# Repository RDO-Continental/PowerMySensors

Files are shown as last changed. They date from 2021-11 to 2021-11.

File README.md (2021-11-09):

# PowerMySensors
Code de notre module de mesure de puissance (Arduino + NRF + MySensors)

Mesure de puissance club RDO : MPRDO V1.0
 * Alimenté par un transfo qui sert aussi à la mesure de la puissance reelle.
 * Transmission par module NRF24L01 et protocole Mysensors
 * Basé sur le projet "openenergymonitor.org"

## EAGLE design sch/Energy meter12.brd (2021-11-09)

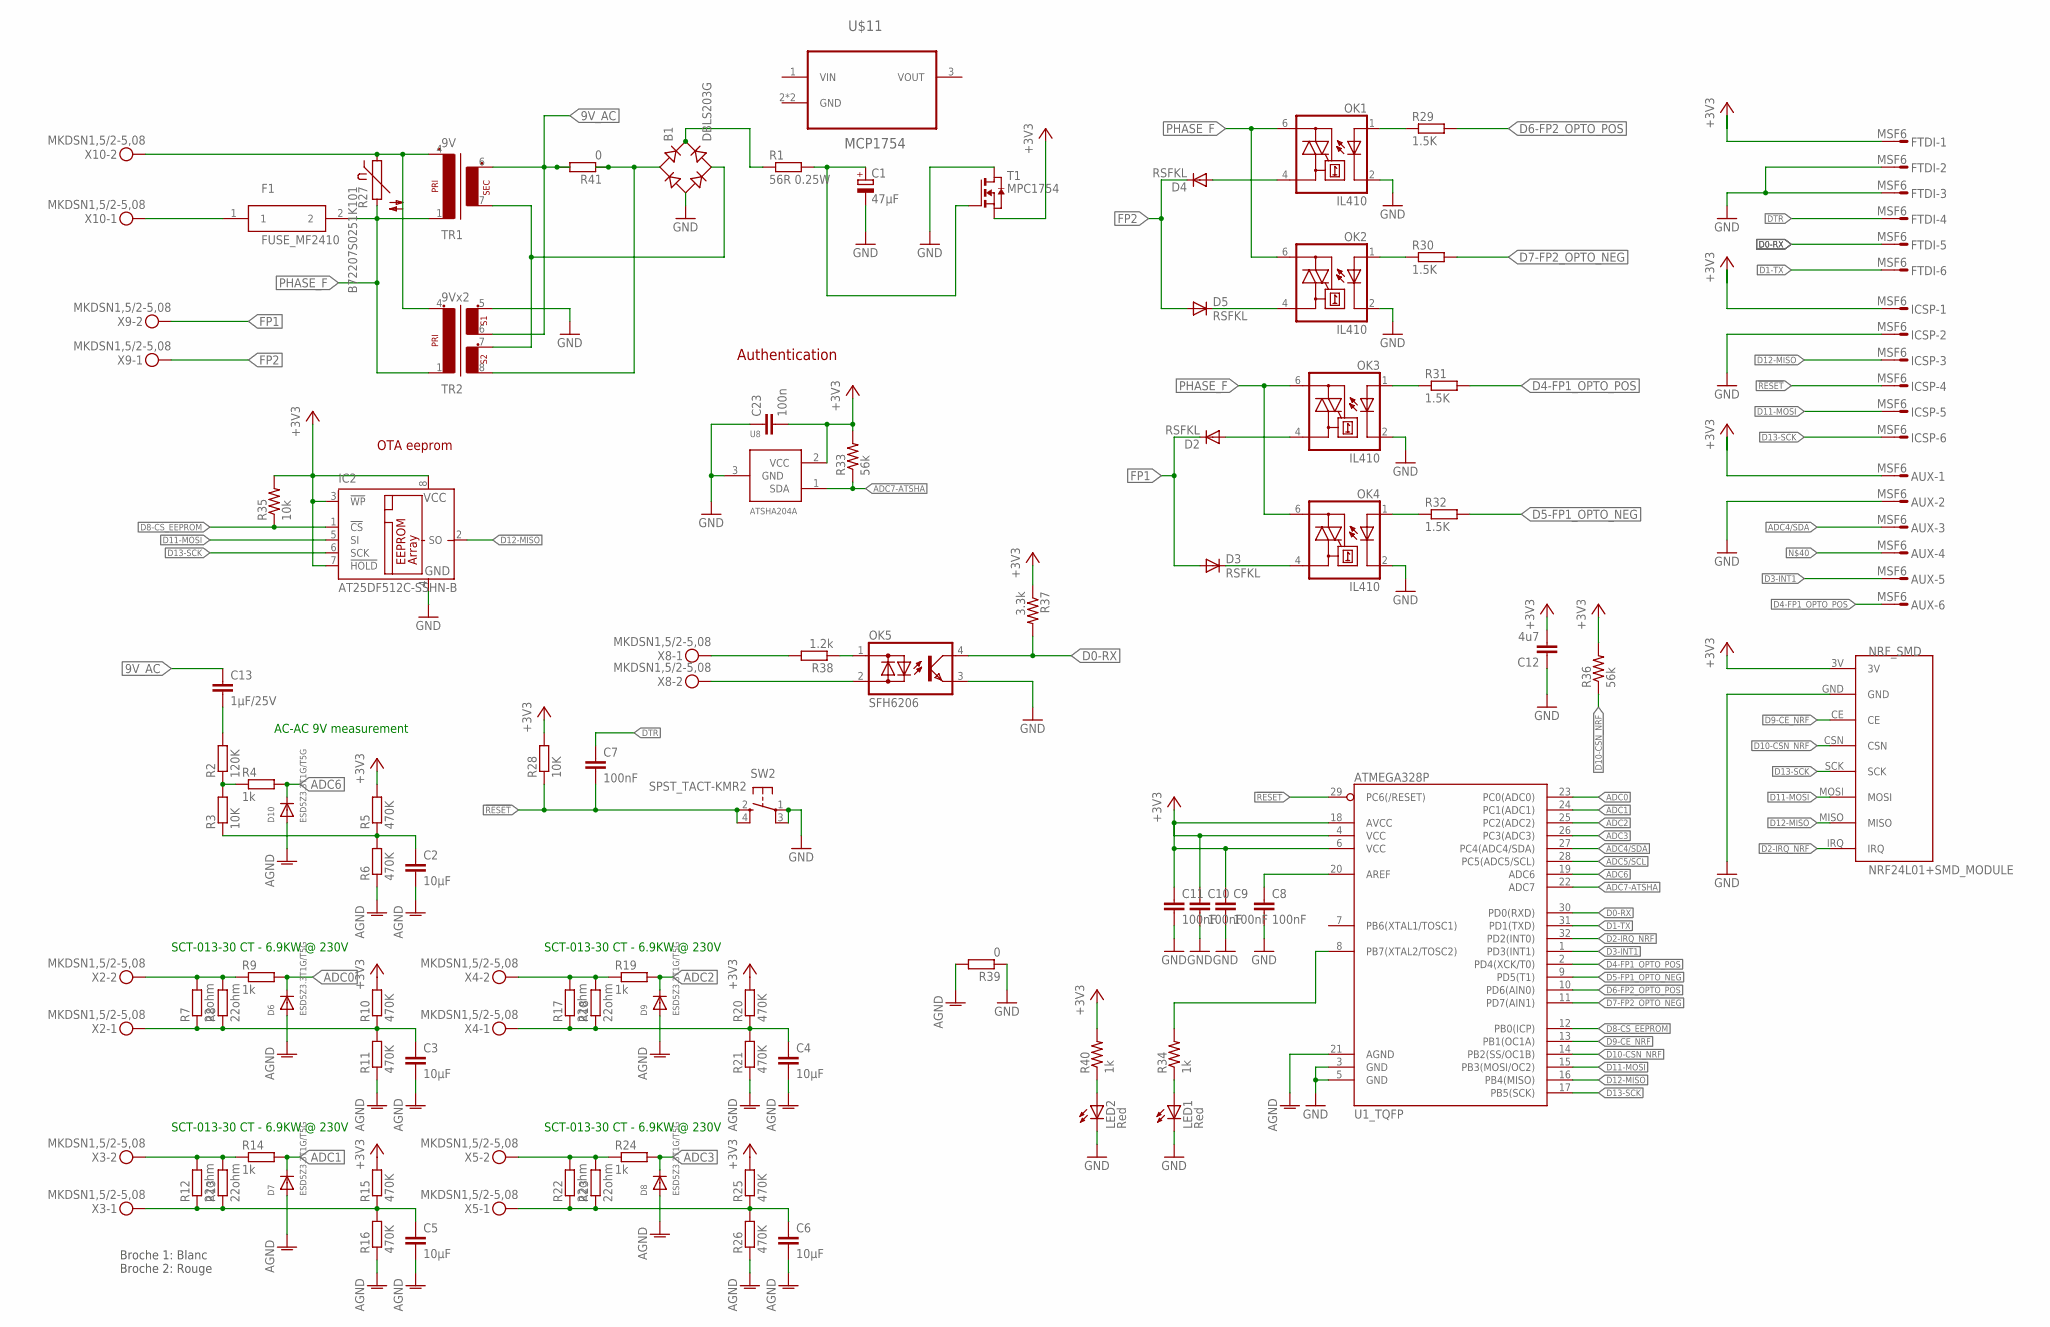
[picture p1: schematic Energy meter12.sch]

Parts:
AUX: MSF6
B1: DBLS203G; DBS
C1: 47µF; PANASONIC_D
C2, C3, C4, C5, C6: 10µF; C0805
C7, C8, C9, C10, C11: 100nF; C0603
C12: 4u7; 0805-CAP
C13: 1µF/25V; C0805
C23: 100n; 0603-CAP
D2, D3, D4, D5: RSFKL; SOD123
D6, D7, D8, D9, D10: ESD5Z3.3T1G/T5G; SOD-523
F1: FUSE_MF2410; 2410
FTDI: MSF6
IC2: AT25DF512C-SSHN-B; SO-08
ICSP: MSF6
LED1, LED2: Red; LED3MM
NRF_SMD: NRF24L01+SMD_MODULE
OK1, OK2, OK3, OK4: IL410; DIL06
OK5: SFH6206; DIL4-SMD
R1: 56R 0.25W; R1206
R2: 120K; R0603
R3, R28: 10K; R0603
R4, R9, R14, R19, R24: 1k; R0603
R5, R6, R10, R11, R15, R16, R20, R21, R25, R26: 470K; R0603
R7, R12, R17, R22: 22ohm; R1206
R8, R13, R18, R23: 22ohm; 0204/7
R27: B72207S0251K101; 07S0251
R29, R30, R31, R32: 1.5K; R0603
R33: 56k; 0603-RES
R34, R40: 1k; 0805-RES
R35: 10k; 0805-RES
R36: 56k; 0805-RES
R37: 3.3k; 0603-RES
R38: 1.2k; 0204/7
R39, R41: 0; R0603
SW2: SPST_TACT-KMR2; KMR2
T1: MPC1754; SOT89
TR1: 9V; PT150901
TR2: 9Vx2; EE20-2
U1_TQFP: ATMEGA328P; TQFP32-08
U8: ATSHA204A; SOT23
U$11: MCP1754; SOT89
X2, X3, X4, X5, X8, X9, X10: MKDSN1,5/2-5,08

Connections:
9V_AC: C13.1, R41.2, TR1.6 (S3), TR2.6 (4)
!RESET: C7.2, ICSP.4, R28.1, SW2.2 (S), SW2.4 (S1), U1_TQFP.29 (PC6(/RESET))
+3V3: AUX.1, C9.1, C10.1, C11.1, C12.2, C23.2, FTDI.1, IC2.3 (!WP), IC2.7 (!HOLD), IC2.8 (VCC), ICSP.1, NRF_SMD.3V, R5.2, R10.2, R15.2, R20.2, R25.2, R28.2, R33.2, R35.2, R36.2, R37.1, R40.2, T1.3 (S), U1_TQFP.4 (VCC), U1_TQFP.6 (VCC), U1_TQFP.18 (AVCC), U8.2 (VCC)
ADC0: D6.K (C), R9.2, U1_TQFP.23 (PC0(ADC0))
ADC1: D7.K (C), R14.2, U1_TQFP.24 (PC1(ADC1))
ADC2: D9.K (C), R19.2, U1_TQFP.25 (PC2(ADC2))
ADC3: D8.K (C), R24.2, U1_TQFP.26 (PC3(ADC3))
ADC4/SDA: AUX.3, U1_TQFP.27 (PC4(ADC4/SDA))
ADC5/SCL: U1_TQFP.28 (PC5(ADC5/SCL))
ADC6: D10.K (C), R4.2, U1_TQFP.19 (ADC6)
ADC7-ATSHA: R33.1, U1_TQFP.22 (ADC7), U8.1 (SDA)
AGND: C2.2, C3.2, C4.2, C5.2, C6.2, D6.A, D7.A, D8.A, D9.A, D10.A, R6.1, R11.1, R16.1, R21.1, R26.1, R39.2, U1_TQFP.21 (AGND)
D0-RX: FTDI.5, OK5.4 (C), R37.2, U1_TQFP.30 (PD0(RXD))
D1-TX: FTDI.6, U1_TQFP.31 (PD1(TXD))
D2-IRQ_NRF: NRF_SMD.IRQ, U1_TQFP.32 (PD2(INT0))
D3-INT1: AUX.5, U1_TQFP.1 (PD3(INT1))
D4-FP1_OPTO_POS: AUX.6, R31.2, U1_TQFP.2 (PD4(XCK/T0))
D5-FP1_OPTO_NEG: R32.2, U1_TQFP.9 (PD5(T1))
D6-FP2_OPTO_POS: R29.2, U1_TQFP.10 (PD6(AIN0))
D7-FP2_OPTO_NEG: R30.2, U1_TQFP.11 (PD7(AIN1))
D8-CS_EEPROM: IC2.1 (!CS), R35.1, U1_TQFP.12 (PB0(ICP))
D9-CE_NRF: NRF_SMD.CE, U1_TQFP.13 (PB1(OC1A))
D10-CSN_NRF: NRF_SMD.CSN, R36.1, U1_TQFP.14 (PB2(SS/OC1B))
D11-MOSI: IC2.5 (SI), ICSP.5, NRF_SMD.MOSI, U1_TQFP.15 (PB3(MOSI/OC2))
D12-MISO: IC2.2 (SO), ICSP.3, NRF_SMD.MISO, U1_TQFP.16 (PB4(MISO))
D13-SCK: IC2.6 (SCK), ICSP.6, NRF_SMD.SCK, U1_TQFP.17 (PB5(SCK))
DTR: C7.1, FTDI.4
FP1: D2.C, D3.A, X9.2
FP2: D4.C, D5.A, X9.1
GND: AUX.2, B1.-, C1.-, C8.2, C9.2, C10.2, C11.2, C12.1, C23.1, FTDI.2, FTDI.3, IC2.4 (GND), ICSP.2, LED1.K (C), LED2.K (C), NRF_SMD.GND, OK1.2 (C), OK2.2 (C), OK3.2 (C), OK4.2 (C), OK5.3 (E), R39.1, SW2.1, SW2.3 (P1), T1.2 (D), T1.2@1 (D), TR2.5 (3), U1_TQFP.3 (GND), U1_TQFP.5 (GND), U8.3 (GND)
unnamed: B1.AC1, R41.1, TR2.8 (6)
unnamed: C1.+, R1.2, T1.1 (G)
unnamed: R2.1, R3.2, R4.1
unnamed: C2.1, R3.1, R5.1, R6.2
unnamed: D4.A, OK1.4 (A1)
unnamed: R7.2, R8.2, R9.1, X2.2
unnamed: C3.1, R7.1, R8.1, R10.1, R11.2, X2.1
unnamed: LED2.A, R40.1
unnamed: R12.2, R13.2, R14.1, X3.2
unnamed: C5.1, R12.1, R13.1, R15.1, R16.2, X3.1
unnamed: R17.2, R18.2, R19.1, X4.2
unnamed: C4.1, R17.1, R18.1, R20.1, R21.2, X4.1
unnamed: R22.2, R23.2, R24.1, X5.2
unnamed: C6.1, R22.1, R23.1, R25.1, R26.2, X5.1
unnamed: C8.1, U1_TQFP.20 (AREF)
unnamed: D2.A, OK3.4 (A1)
unnamed: D5.C, OK2.4 (A1)
unnamed: OK1.1 (A), R29.1
unnamed: OK2.1 (A), R30.1
unnamed: R38.2, X8.1
unnamed: D3.C, OK4.4 (A1)
unnamed: OK3.1 (A), R31.1
unnamed: OK4.1 (A), R32.1
unnamed: OK5.1 (AC1), R38.1
unnamed: OK5.2 (AC2), X8.2
unnamed: B1.+, R1.1
unnamed: C13.2, R2.2
unnamed: LED1.A, R34.1
unnamed: R34.2, U1_TQFP.8 (PB7(XTAL2/TOSC2))
unnamed: R27.1, TR1.4 (P2), TR2.4 (2), X10.2
unnamed: B1.AC2, TR1.7 (S4), TR2.7 (5)
unnamed: F1.1, X10.1
PHASE_F: F1.2, OK1.6 (A2), OK2.6 (A2), OK3.6 (A2), OK4.6 (A2), R27.2, TR1.1, TR2.1

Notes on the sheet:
AC-AC 9V measurement
SCT-013-30 CT - 6.9KW @ 230V
Broche 1: Blanc Broche 2: Rouge
Authentication
OTA eeprom

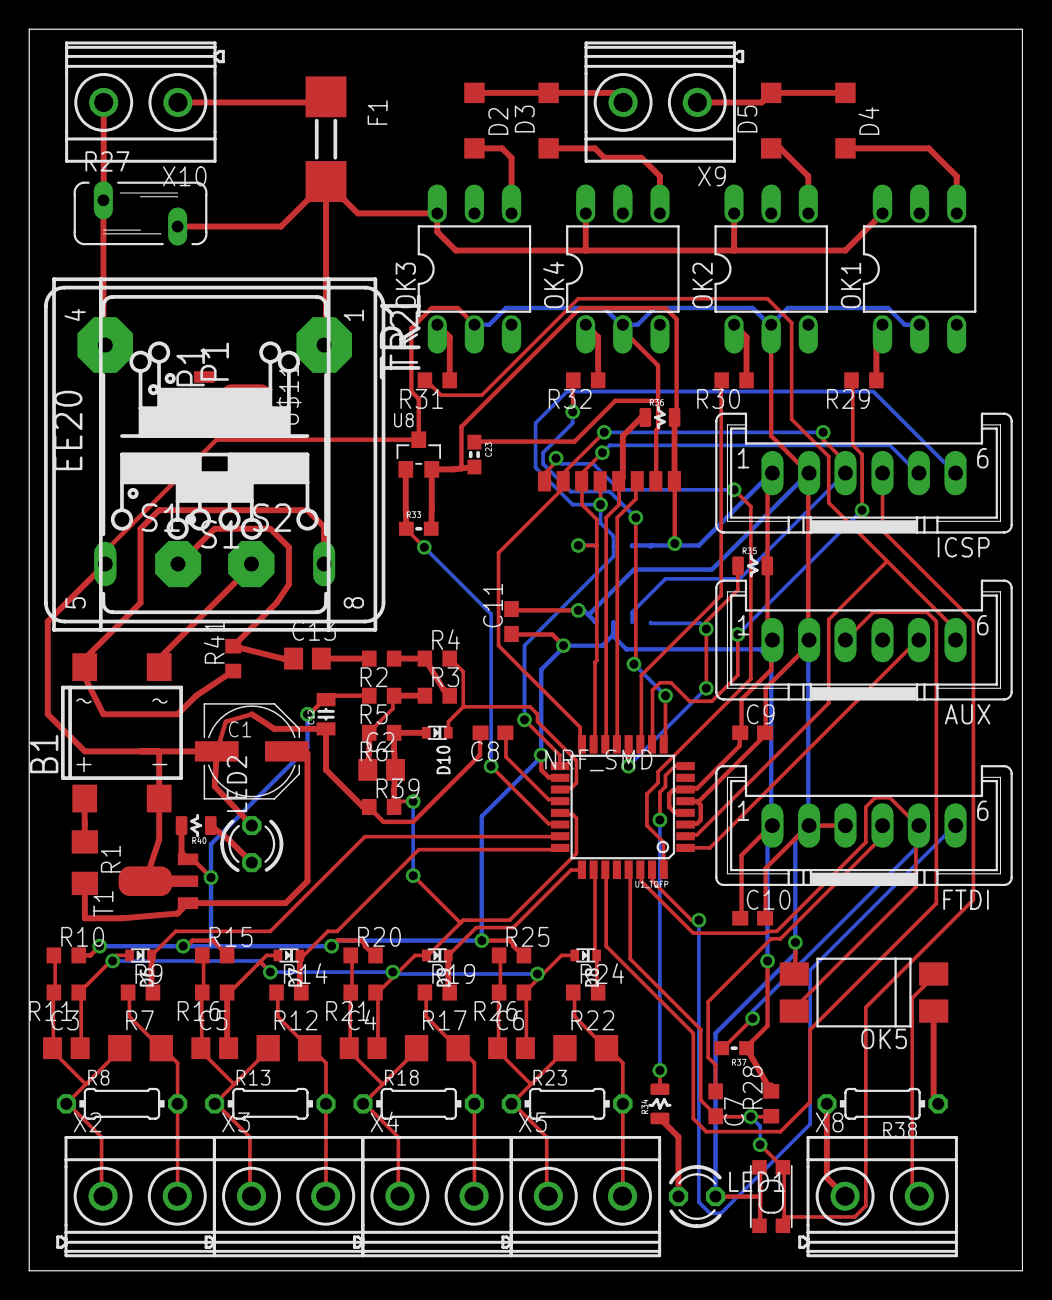
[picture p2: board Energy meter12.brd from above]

Board: 2 copper layers, 68.0 x 85.0 mm, 92 parts (1 on the bottom side), 62 nets.

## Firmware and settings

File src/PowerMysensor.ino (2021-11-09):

/* Mesure de puissance club RDO : MPRDO V1.0
 * Alimenté par un transfo qui sert aussi à la mesure de la puissance reelle.
 * Transmission par module NRF24L01 et protocole Mysensors
 * Basé sur le projet "openenergymonitor.org"
 */
#define MY_DEBUG 
#include "SSD1306Ascii.h"
#include "SSD1306AsciiAvrI2c.h"
#include <SPI.h>

// 0X3C+SA0 - 0x3C or 0x3D
#define I2C_ADDRESS 0x3C

SSD1306AsciiAvrI2c oled;

/* RADIO Part */ 
#define MY_RADIO_RF24
#include "MySensors.h"

#include "EmonLib.h"             // Include Emon Library
EnergyMonitor emon1;             // Create an instance
EnergyMonitor emon2;             // Create an instance
EnergyMonitor emon3;             // Create an instance
EnergyMonitor emon4;             // Create an instance

boolean DEBUG = 0;                       // Print serial debug

//http://openenergymonitor.org/emon/buildingblocks/calibration

const float Ical1=                90.9;                                 // (2000 turns / 22 Ohm burden) = 90.9
const float Ical2=                90.9;                                 // (2000 turns / 22 Ohm burden) = 90.9
const float Ical3=                90.9;                                 // (2000 turns / 22 Ohm burden) = 90.9
const float Ical4=                16.67;                               // (2000 turns / 120 Ohm burden) = 16.67

float Vcal=                       220;//545;
const float phase_shift=          1.7;
//----------------------------MPRDO V1.0 cablage---------------------------------------------------------------------------------------------------------------
const int  LEDpin=                 DDB7; // emonTx V3 LED
const byte DIP_switch1=            8; // 
const byte DIP_switch2=            9; // 
const byte pulse_countINT=         1; // INT 1 / Dig 3 Terminal Block / RJ45 Pulse counting pin(emonTx V3.4) - (INT0 / Dig2 emonTx V3.2)
const byte pulse_count_pin=        3; // INT 1 / Dig 3 Terminal Block / RJ45 Pulse counting pin(emonTx V3.4) - (INT0 / Dig2 emonTx V3.2)
const int  AcVin=                 A6; // Tension apres le transfo 9V
const int  Ipow1=                 A0; // Premiere sonde en courant
const int  Ipow2=                 A1; // Seconde sonde en courant
const int  Ipow3=                 A2; // Troisieme sonde en courant
const int  Ipow4=                 A3; // Quatrieme sonde en courant
const int  Fp1OptoNeg=             4; // Fil pilote 1 : Partie negative de la sinusoide
const int  Fp1OptoPos=             5; // Fil pilote 1 : Partie positive de la sinusoide
const int  Fp2OptoNeg=             6; // Fil pilote 2 : Partie negative de la sinusoide
const int  Fp2OptoPos=             7; // Fil pilote 2 : Partie positive de la sinusoide
const int  PulseCnt=               0; // Comptage de pulse du compteur EDF
//-------------------------------------------------------------------------------------------------------------------------------------------

//-----------------------Config MySensor----------------------------------------------------------------------------------------------------
#define CHILD_ID_REAL_POWER 0
#define CHILD_ID_APPARENT_POWER 1
#define CHILD_ID_POWER_FACTOR 2
#define CHILD_ID_VOLTAGE 3
#define CHILD_ID_CURRENT_1 4
#define CHILD_ID_CURRENT_2 5
#define CHILD_ID_CURRENT_3 6
#define CHILD_ID_CURRENT_4 7

unsigned long lastSend;
unsigned long SEND_FREQUENCY = 1000; // Minimum time between send (in milliseconds). We don't wnat to spam the gateway.
unsigned long lastSend2;
unsigned long SEND_FREQUENCY2 = 1000;//300000; // Minimum time between send (in milliseconds). We don't wnat to spam the gateway.
bool metric = true;

MyMessage realPowerMsg(CHILD_ID_REAL_POWER,V_WATT);
MyMessage apparentPowerMsg(CHILD_ID_APPARENT_POWER,V_VA);
MyMessage powerFActorMsg(CHILD_ID_POWER_FACTOR,V_POWER_FACTOR);
MyMessage supplyVoltageMsg(CHILD_ID_VOLTAGE,V_VOLTAGE);
MyMessage IrmsMsg1(CHILD_ID_CURRENT_1,V_CURRENT);
MyMessage IrmsMsg2(CHILD_ID_CURRENT_2,V_CURRENT);
MyMessage IrmsMsg3(CHILD_ID_CURRENT_3,V_CURRENT);
MyMessage IrmsMsg4(CHILD_ID_CURRENT_4,V_CURRENT);


#define MOC_P 4 // MOC phase positive
#define MOC_N 5 // MOC phase négative

#define CHILD_ID_FP 10 // Identifiant du capteur

typedef struct {
   char mode_code;
   int code_p;
   int code_n;
} modeFilPilote;

modeFilPilote modesFilPilote[4] = {
  {'O', 1, 0}, // Mode Off
  {'G', 0, 1}, // Mode hors gel
  {'E', 1, 1}, // Mode éco
  {'C', 0, 0}  // Mode confort
};

void presentation()  
{ 
  DDRB |= (1 << DDB7); // Led output
  BlinkLed();
  // Send the sketch version information to the gateway
  sendSketchInfo("Energy Meter x 3v2", "1.2");
  // Register all sensors to gw (they will be created as child devices)
  present(CHILD_ID_REAL_POWER, S_POWER); // Register this device as power sensor
  present(CHILD_ID_APPARENT_POWER, S_POWER); // Register this device as power sensor
  present(CHILD_ID_POWER_FACTOR, S_POWER); // Register this device as power sensor
  present(CHILD_ID_VOLTAGE, S_MULTIMETER); // Register this device as power sensor
  present(CHILD_ID_CURRENT_1, S_MULTIMETER); // Register this device as power sensor
  present(CHILD_ID_CURRENT_2, S_MULTIMETER); // Register this device as power sensor
  present(CHILD_ID_CURRENT_3, S_MULTIMETER); // Register this device as power sensor
  present(CHILD_ID_CURRENT_4, S_MULTIMETER); // Register this device as power sensor
  metric = getControllerConfig().isMetric;

  /* FIL PILOTE */
  //sendSketchInfo("Fil pilote", "2.0");
  present(CHILD_ID_FP, S_CUSTOM);
  pinMode(MOC_P, OUTPUT);
  pinMode(MOC_N, OUTPUT);
  // Restauration du mode sauvegardé
  //digitalWrite(MOC_P, loadState(MOC_P));
  //digitalWrite(MOC_N, loadState(MOC_N));

}

void setup()
{  
  oled.begin(&Adafruit128x64, I2C_ADDRESS);
  oled.setFont(Adafruit5x7);

  oled.clear();
  oled.set2X();
  oled.println("Hello RDO!");
  oled.println("A long line may be truncated");
  oled.println();
  /*oled.set2X();
  oled.println("2X demo");
  oled.set1X();
  oled.print("\nmicros: ");*/
  
  DDRB |= (1 << DDB7); // Led output
  emon1.voltage(AcVin, Vcal, phase_shift);  // Voltage: input pin, calibration, phase_shift
  emon1.current(Ipow1, Ical1);       // 60.6 Current: input pin, calibration.
  emon2.voltage(AcVin, Vcal, phase_shift);  // Voltage: input pin, calibration, phase_shift
  emon2.current(Ipow2, Ical2);       // 60.6 Current: input pin, calibration.
  emon3.voltage(AcVin, Vcal, phase_shift);  // Voltage: input pin, calibration, phase_shift
  emon3.current(Ipow3, Ical3);       // 60.6 Current: input pin, calibration.
  emon4.voltage(AcVin, Vcal, phase_shift);  // Voltage: input pin, calibration, phase_shift
  emon4.current(Ipow4, Ical4);       // 60.6 Current: input pin, calibration.
  BlinkLed();
}

void loop()
{
  unsigned long now = millis();
  emon1.calcVI(20,2000);         // Calculate all. No.of half wavelengths (crossings), time-out
  //emon1.serialprint();           // Print out all variables (realpower, apparent power, Vrms, Irms, power factor)
  emon2.calcVI(20,2000);         // Calculate all. No.of half wavelengths (crossings), time-out
  //emon2.serialprint();           // Print out all variables (realpower, apparent power, Vrms, Irms, power factor)
  emon3.calcVI(20,2000);         // Calculate all. No.of half wavelengths (crossings), time-out
  //emon3.serialprint();           // Print out all variables (realpower, apparent power, Vrms, Irms, power factor)
  emon4.calcVI(20,2000);         // Calculate all. No.of half wavelengths (crossings), time-out
  //emon4.serialprint();           // Print out all variables (realpower, apparent power, Vrms, Irms, power factor)
  bool sendTime = now - lastSend > SEND_FREQUENCY;
  if (sendTime) { 

    float realPower       = emon1.realPower;        //extract Real Power into variable
    if (DEBUG==1)
    { 
      Serial.print("Real power=");
      Serial.println(realPower);
    }
    if(realPower >= 0 && realPower < 10000){
      send(realPowerMsg.set(realPower,1));
    }
    else { 
      send(realPowerMsg.set(0.0,1));
      } 
    lastSend = now;
  }
  BlinkLed();
  bool sendTime2 = now - lastSend2 > SEND_FREQUENCY2;
  if(sendTime2){
    
    float apparentPower   = emon1.apparentPower;    //extract Apparent Power into variable
    float powerFactor     = emon1.powerFactor;      //extract Power Factor into Variable
    float supplyVoltage   = emon1.Vrms;             //extract Vrms into Variable
    float Irms            = emon1.Irms;             //extract Irms into Variable
    if (DEBUG==1)
    { 
      Serial.print("Apparent power=");
      Serial.println(apparentPower);
      Serial.print("Power factor=");
      Serial.println(powerFactor);
      Serial.print("Volts=");
      Serial.println(supplyVoltage);
      Serial.print("Irms=");
      Serial.println(Irms);
    }
    if(apparentPower >= 0 && apparentPower < 10000){
      send(apparentPowerMsg.set(apparentPower,2));
    }
    if(powerFactor >= 0 && powerFactor < 10000){
      send(powerFActorMsg.set(powerFactor,3));
    }
    if(supplyVoltage >= 0 && supplyVoltage < 1000){
      send(supplyVoltageMsg.set(supplyVoltage,5));
    }
    if(Irms >= 0 && Irms < 1000){   
      send(IrmsMsg1.set(Irms,5));
    }
    lastSend2 = now;

  }
    AfficheResult();  
}
void AfficheResult(void) {
    oled.clear();
    /*oled.set2X();
    oled.println("Hello RDO!");*/
    oled.set1X();
    oled.print("Real Power 1 : ");
    oled.println(emon1.realPower);
    oled.print("Apparent power=");
      oled.println(emon1.apparentPower);
      oled.print("Power factor=");
      oled.println(emon1.powerFactor);
      oled.print("Volts=");
      oled.println(emon1.Vrms);
      oled.print("Irms=");
      oled.println(emon1.Irms);
      oled.print("Time=");
      oled.println(millis());
}
void BlinkLed(void) {
  if ((PORTB & (1 << DDB7))==1 ) {
    Serial.println("Led On");
    PORTB &= ~(1 << DDB7);
  }
  else {
    PORTB |= (1 << DDB7);
    Serial.println("Led Off");
  }
}

void receive(const MyMessage &message) {
  if (message.type == V_HVAC_FLOW_STATE) {
    for(int i=0; i < 4; i++) {
      if(message.getString()[0] == modesFilPilote[i].mode_code) {
        digitalWrite(MOC_P, modesFilPilote[i].code_p);
        digitalWrite(MOC_N, modesFilPilote[i].code_n);
        
        // Sauvegarde du mode
        //saveState(MOC_P, modesFilPilote[i].code_p);
        //saveState(MOC_N, modesFilPilote[i].code_n);
        return;
      }
    }
  }
}

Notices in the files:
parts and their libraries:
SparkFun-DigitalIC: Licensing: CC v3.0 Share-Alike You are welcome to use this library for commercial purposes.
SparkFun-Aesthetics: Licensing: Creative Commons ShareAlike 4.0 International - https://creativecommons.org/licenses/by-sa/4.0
